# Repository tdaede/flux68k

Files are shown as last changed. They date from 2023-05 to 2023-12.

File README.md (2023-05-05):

flux68k
=======

The flux68k is an adapter board that allows usage of Gotek floppy drive emulators running [FlashFloppy](https://github.com/keirf/flashfloppy) firmware with the Sharp X68000 line of computers.

Requirements
------------

1. Two Gotek floppy emulators based on the AT32F435 with SFRKC30.AT4.35 PCB revision (sold as FlashFloppy+ compatible).

2. Two USB flash drives.

3. flux68k PCB.

4. DC +5V power supply with a 6x2.1mm center positive barrel jack (unless using auto switch board)

5. Male to male DB37 cable.

Installation
------------

1. Set the jumpers on each of the Gotek emulators to S0 and MOR.

2. Install the emulators into the flux68k PCB, being careful to line up the power connectors.

3. Plug in the +5V power supply and ensure that both emulators power on.

4. Build the following branch of FlashFloppy, and flash it to to the Gotek. https://github.com/keirf/flashfloppy/pull/781

5. Copy the [example FF.CFG](https://github.com/keirf/flashfloppy/blob/a0a06fc15bd6ab05d6b62a67390bd5e57fd1853e/examples/FF.CFG) to each of the USB sticks and change the pin02 line to:
``` ini
pin02 = in
```

6. Set the switch on the back of the flux68k to drives 2-3.

7. Plug in the DB37 cable between the X68000 and the flux68k.

Usage
-----

Copy floppy images to the USB flash drives and access or boot from them from the X68000. More detailed information on using FlashFloppy can be found at (FlashFloppy's documentation)[https://github.com/keirf/flashfloppy/wiki].

Notes
-----

* XDF images must be renamed to have the .img extension.

* Many applications do not boot correctly from drives 2-3. For these, the rear switch must be set to drives 0-1, and the X68000's internal drives disconnected (unless the auto switch board is used, see below). On compact models, there is a switch on the back of the X68000 to switch the internal drive assigments to 2-3.

* The flux68k must be powered when attached to the X68000 or floppies may not read correctly.

* FlashFloppy currently ignores the motorized eject signal, so the floppy must be manually ejected (by pushing the rotary knob) if an application tries to automatically eject a floppy.

Auto switch board
=================

Optionally, a mod can be installed on non-compact models to automatically switch the internal floppy drive assignments. In addition, this board will also supply power to the external floppy emulators, so that an external power supply is not needed.

Requirements
------------

1. Auto switcher board

2. 34 pin IDC cable, at least 20cm Long

3. +5V internal power cable, either a [Molex to berg connector cable](https://www.crystalfontz.com/product/wrpwry12-four-pin-power-splitter-cable) or a custom made cable that attaches to one of the 3 pin berg connections for the floppy drives or HDD.

Installation
------------

1. Remove the left panel of the X68000.

2. Disconnect the SCSI cable from the external SCSI connector PCB, if present.

3. Disconnect the floppy cable from the external floppy connector PCB.

4. Unscrew and remove the SCSI/floppy connector module via the two plastic tapping screws holding it in place.

5. Remove the SCSI connector PCB from the module by removing the two machine screws holding it in place.

6. Remove the floppy connector PCB from the mdoule by removing the two machine screws holding it in place. Note the relative positions of the bracket and EMI shielding.

7. Attach the new 34 pin IDC cable to the "MB" connector on the auto switcher PCB.

8. Attach the +5V power cable to the swapper PCB.

9. Install the auto switcher PCB on the original metal bracket / EMI shield using the two machine screws.

10. Install the SCSI connector board (if present) on top of the swapper PCB with two machine screws.

11. Install the external connector module back into the X68000 using the two plastic tapping screws.

12. Attach the +5V cable to the appropriate location (the molex connector if using a molex to berg cable).

13. Connect the existing 34 pin floppy IDC cable coming off of the floppy drives to the "FD" connector on the swapper PCB.

14. Disconnect the other end of the existing 34 pin floppy IDC cable from the motherboard connector at the base of the X68000. Leave this disconnected inside the machine.

15. Connect the other end of the new 34 pin IDC cable (connected to the "MB" connector on the switcher PCB) to the motherboard connector at the base of the X68000.

16. Reinstall the left panel of the X68000.

Notes
-----

* The auto switcher PCB uses the previously unused pin 3 of the 37-pin connector as the switch signal. When left floating or high, it switches the internal drives to 0-1. When pulled low, it switches the internal drives to 2-3.

* The auto swticher PCB uses unused pins 18 and 19 of the 37-pin connector to send +5V power to the external floppy emulator. Each pin is protected by a 250mA PTC fuse.

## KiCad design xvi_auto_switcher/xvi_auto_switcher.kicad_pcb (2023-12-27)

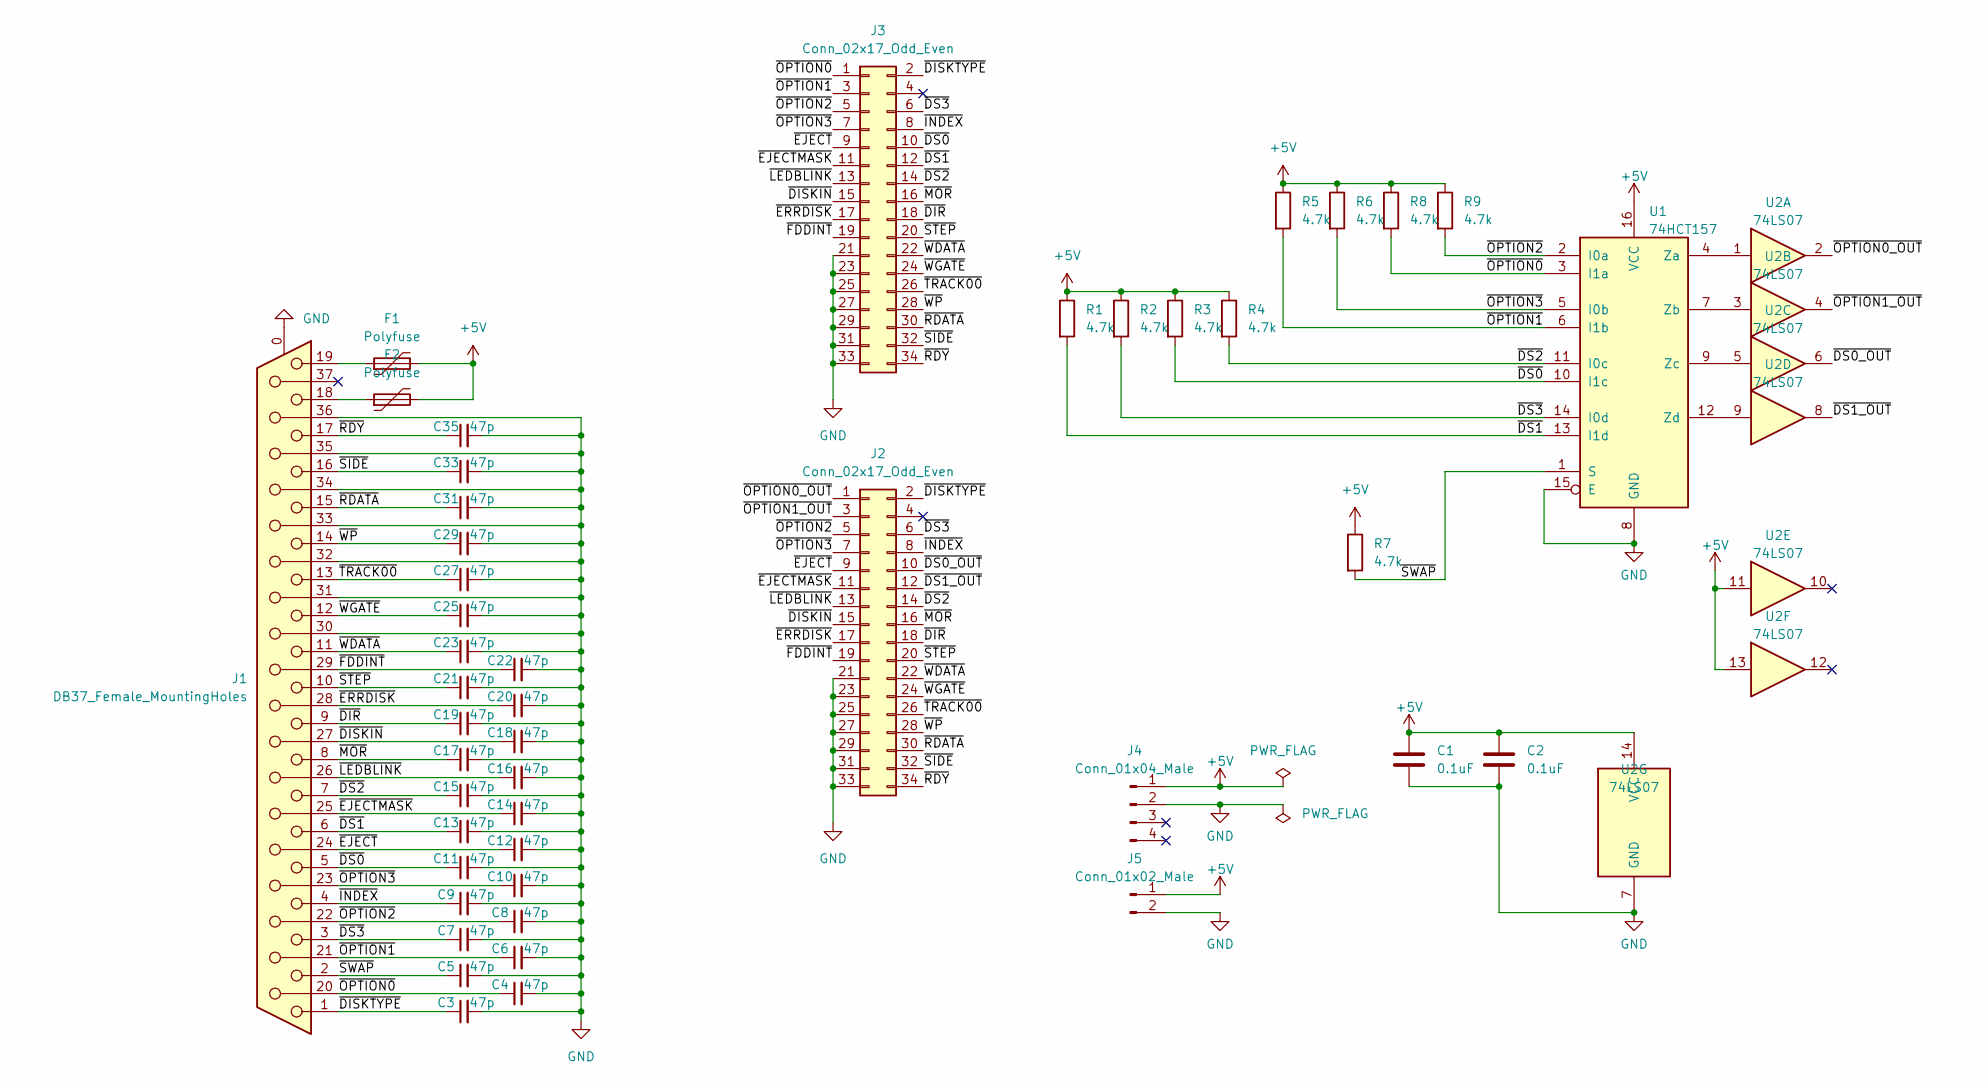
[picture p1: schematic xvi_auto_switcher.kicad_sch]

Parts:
C1, C2: 0.1uF; C_0603_1608Metric; Digikey 311-1088-1-ND
C3, C4, C5, C6, C7, C8, C9, C10, C11, C12, C13, C14, C15, C16, C17, C18, C19, C20, C21, C22, C23, C25, C27, C29, C31, C33, C35: 47p; C_0603_1608Metric; Digikey 311-1065-1-ND
F1, F2: Polyfuse; R_1206_3216Metric; Digikey 507-1799-1-ND
J1: DB37_Female_MountingHoles; DSUB-37_Female_Horizontal_P2.77x2.84mm_EdgePinOffset7.70mm_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; Digikey A32114-ND
J2, J3: Conn_02x17_Odd_Even; IDC-Header_2x17_P2.54mm_Vertical; Digikey ED10528-ND
J4: Conn_01x04_Male; PinHeader_1x04_P2.54mm_Horizontal; Digikey A112643-ND
J5: Conn_01x02_Male; PinHeader_1x02_P2.54mm_Vertical; Digikey DNP
R1, R2, R3, R4, R5, R6, R7, R8, R9: 4.7k; R_0603_1608Metric; Digikey 311-4.70KHRCT-ND
U1: 74HCT157; SOIC-16_3.9x9.9mm_P1.27mm; Digikey 296-31835-1-ND
U2: 74LS07; SOIC-14_3.9x8.7mm_P1.27mm; Digikey 296-14877-1-ND

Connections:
+5V: C1.1, C2.1, F1.2, F2.2, J4.1, J5.1, R1.1, R2.1, R3.1, R4.1, R5.1, R6.1, R7.1, R8.1, R9.1, U1.16 (VCC), U2.11, U2.13, U2.14 (VCC)
/~DIR: C19.1, J1.9, J2.18, J3.18
/~DISKIN: C18.1, J1.27, J2.15, J3.15
/~DISKTYPE: C3.1, J1.1, J2.2, J3.2
/~DS0_OUT: J2.10, U2.6
/~DS0: C11.1, J1.5, J3.10, R3.2, U1.10 (I1c)
/~DS1_OUT: J2.12, U2.8
/~DS1: C13.1, J1.6, J3.12, R1.2, U1.13 (I1d)
/~DS2: C15.1, J1.7, J2.14, J3.14, R4.2, U1.11 (I0c)
/~DS3: C7.1, J1.3, J2.6, J3.6, R2.2, U1.14 (I0d)
/~EJECTMASK: C14.1, J1.25, J2.11, J3.11
/~EJECT: C12.1, J1.24, J2.9, J3.9
/~ERRDISK: C20.1, J1.28, J2.17, J3.17
/~FDDINT: C22.1, J1.29, J2.19, J3.19
/~INDEX: C9.1, J1.4, J2.8, J3.8
/~LEDBLINK: C16.1, J1.26, J2.13, J3.13
/~MOR: C17.1, J1.8, J2.16, J3.16
/~OPTION0_OUT: J2.1, U2.2
/~OPTION0: C4.1, J1.20, J3.1, R8.2, U1.3 (I1a)
/~OPTION1_OUT: J2.3, U2.4
/~OPTION1: C6.1, J1.21, J3.3, R5.2, U1.6 (I1b)
/~OPTION2: C8.1, J1.22, J2.5, J3.5, R9.2, U1.2 (I0a)
/~OPTION3: C10.1, J1.23, J2.7, J3.7, R6.2, U1.5 (I0b)
/~RDATA: C31.1, J1.15, J2.30, J3.30
/~RDY: C35.1, J1.17, J2.34, J3.34
/~SIDE: C33.1, J1.16, J2.32, J3.32
/~STEP: C21.1, J1.10, J2.20, J3.20
/~SWAP: C5.1, J1.2, R7.2, U1.1 (S)
/~TRACK00: C27.1, J1.13, J2.26, J3.26
/~WDATA: C23.1, J1.11, J2.22, J3.22
/~WGATE: C25.1, J1.12, J2.24, J3.24
/~WP: C29.1, J1.14, J2.28, J3.28
GND: C1.2, C2.2, C3.2, C4.2, C5.2, C6.2, C7.2, C8.2, C9.2, C10.2, C11.2, C12.2, C13.2, C14.2, C15.2, C16.2, C17.2, C18.2, C19.2, C20.2, C21.2, C22.2, C23.2, C25.2, C27.2, C29.2, C31.2, C33.2, C35.2, J1.0 (PAD), J1.30, J1.31, J1.32, J1.33, J1.34, J1.35, J1.36, J2.21, J2.23, J2.25, J2.27, J2.29, J2.31, J2.33, J3.21, J3.23, J3.25, J3.27, J3.29, J3.31, J3.33, J4.2, J5.2, U1.8 (GND), U1.15 (E), U2.7 (GND)
unnamed: F1.1, J1.19
unnamed: F2.1, J1.18
unnamed: U1.4 (Za), U2.1
unnamed: U1.7 (Zb), U2.3
unnamed: U1.9 (Zc), U2.5
unnamed: U1.12 (Zd), U2.9

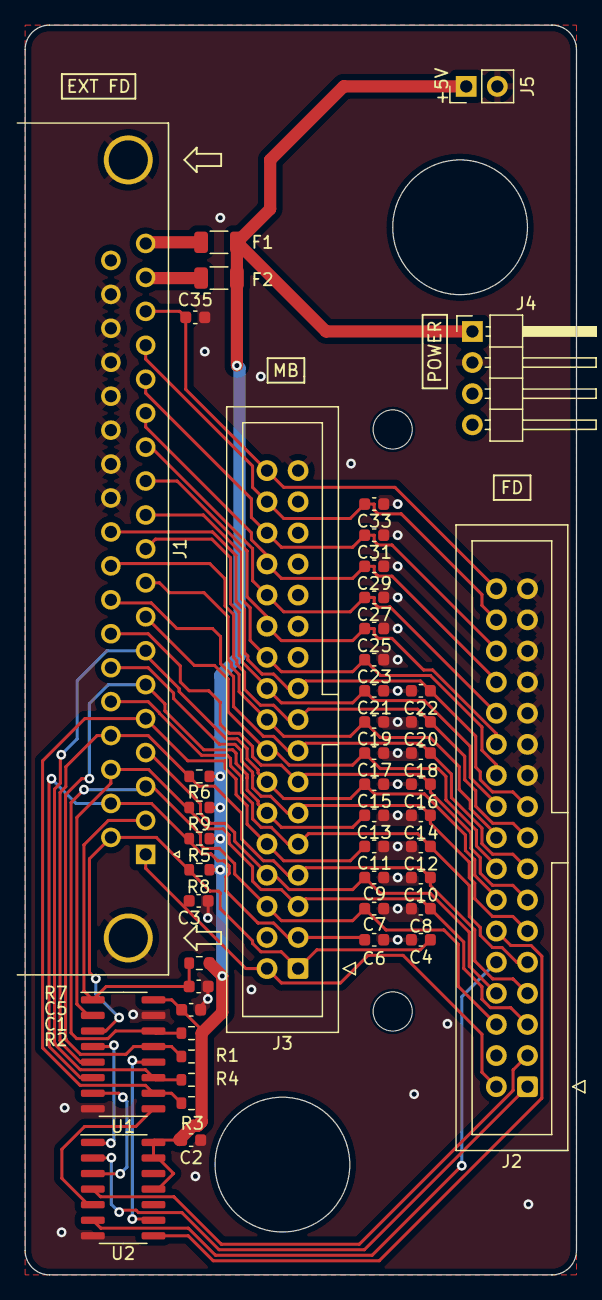
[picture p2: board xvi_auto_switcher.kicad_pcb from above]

Board: 2 copper layers, 45.0 x 102.0 mm, 47 parts (0 on the bottom side), 39 nets.

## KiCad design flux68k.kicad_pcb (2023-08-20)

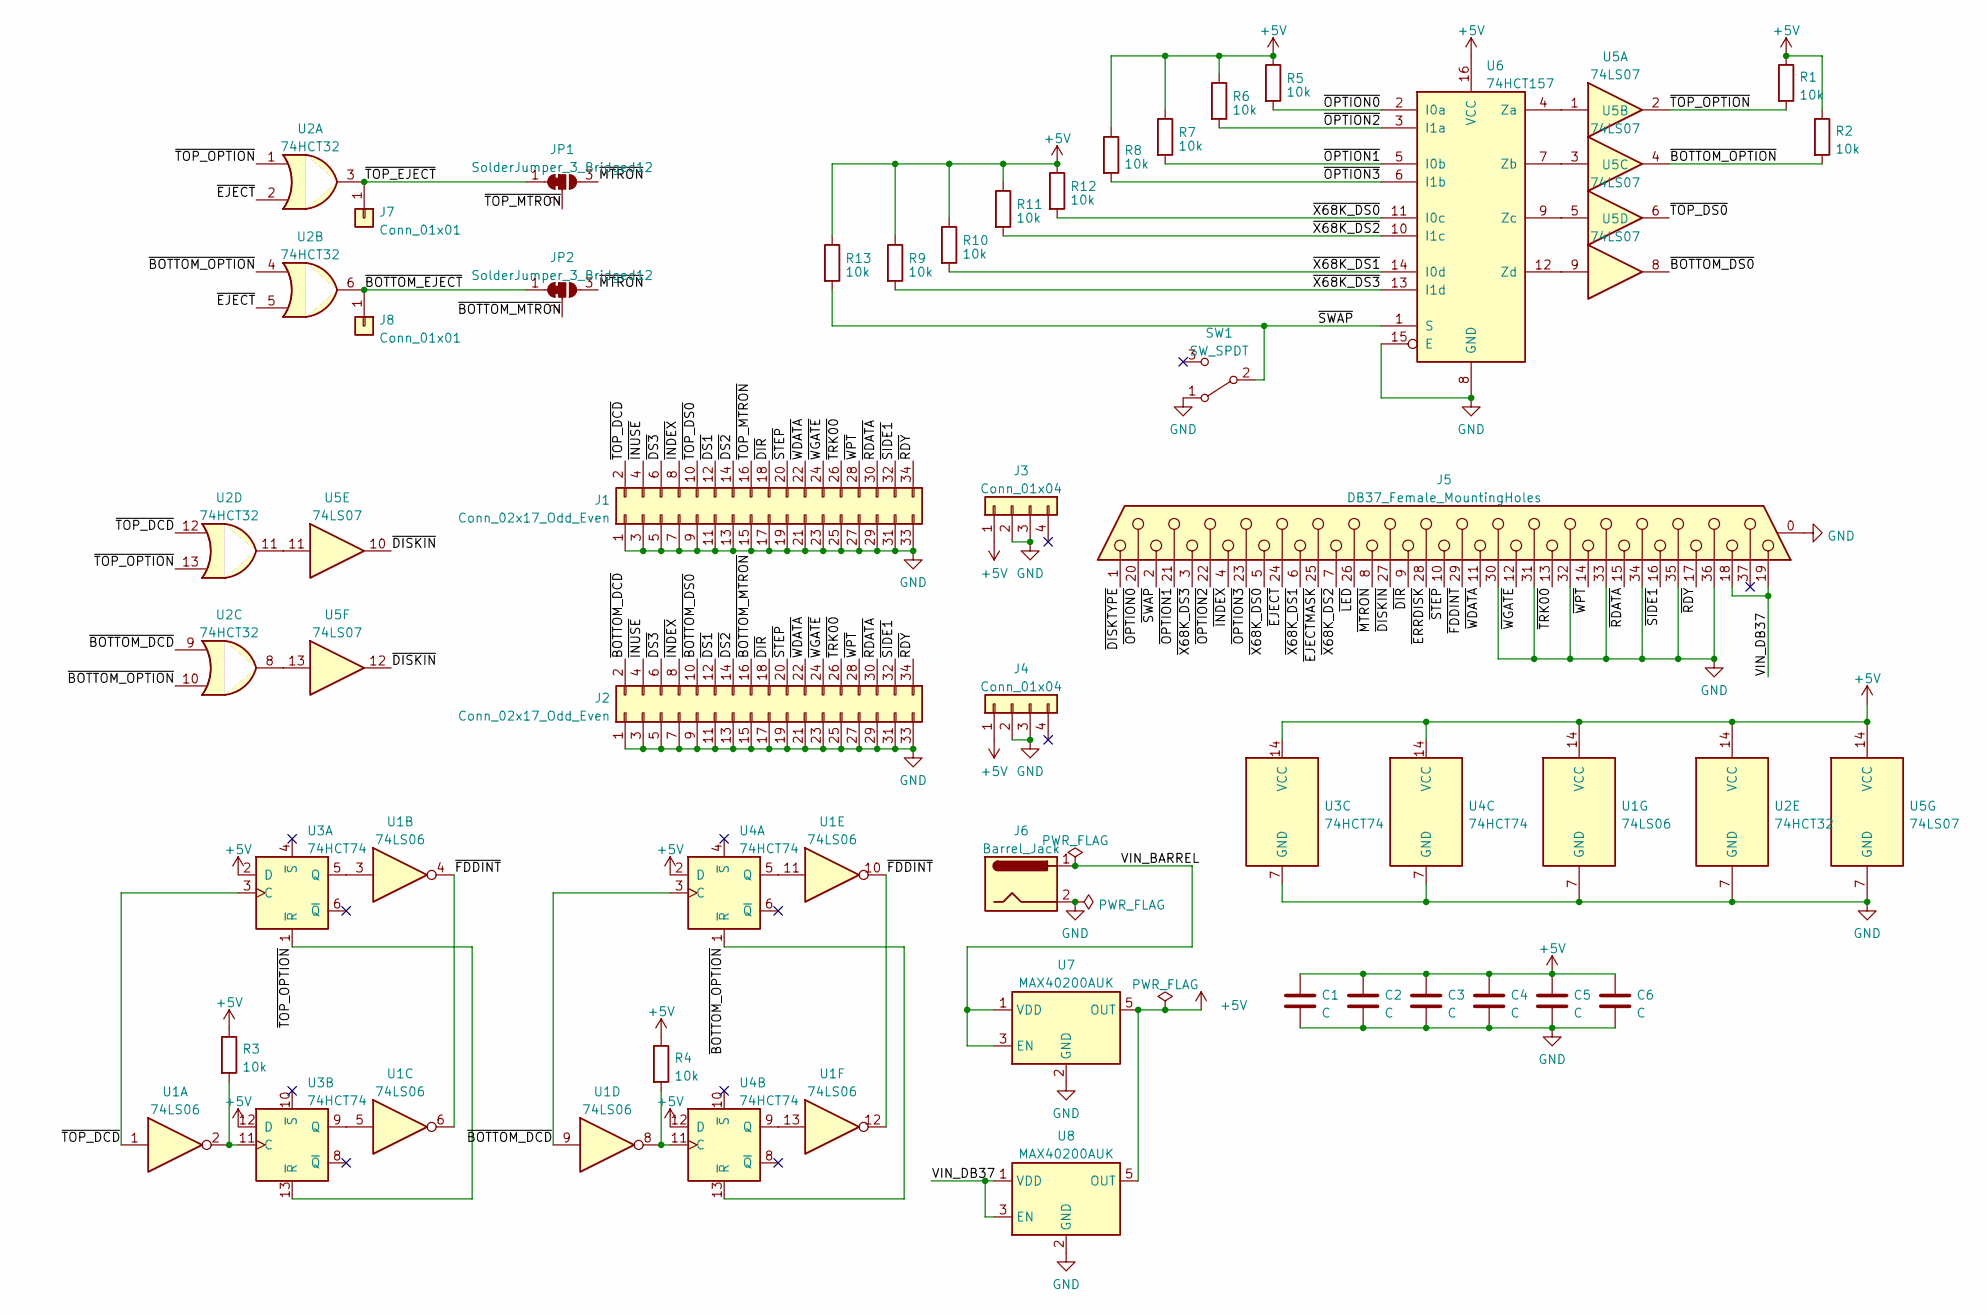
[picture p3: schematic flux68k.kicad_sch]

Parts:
C1, C2, C3, C4, C5, C6: C; C_0805_2012Metric_Pad1.18x1.45mm_HandSolder; Digikey 311-1140-1-ND
J1, J2: Conn_02x17_Odd_Even; PinSocket_2x17_P2.54mm_Vertical; Digikey S9199-ND
J3, J4: Conn_01x04; PinSocket_1x04_P2.54mm_Vertical; Digikey S7037-ND
J5: DB37_Female_MountingHoles; DSUB-37_Female_Vertical_P2.77x2.84mm_MountingHoles; Digikey L77SDCH37SOL2-ND
J6: Barrel_Jack; PJ-044AH; Digikey CP-044AH-ND
J7, J8: Conn_01x01; PinSocket_1x01_P2.54mm_Vertical; Digikey DNP
JP1, JP2: SolderJumper_3_Bridged12; SolderJumper-3_P1.3mm_Bridged2Bar12_Pad1.0x1.5mm; Digikey DNP
R1, R2, R3, R4, R5, R6, R7, R8, R9, R10, R11, R12, R13: 10k; R_0805_2012Metric_Pad1.20x1.40mm_HandSolder; Digikey 311-10.0KCRCT-ND
SW1: SW_SPDT; SW_Slide_1P2T_CK_OS102011MS2Q; Digikey CKN12284-ND
U1: 74LS06; SOIC-14_3.9x8.7mm_P1.27mm; Digikey 296-14876-1-ND
U2: 74HCT32; SOIC-14_3.9x8.7mm_P1.27mm; Digikey 296-14868-1-ND
U3, U4: 74HCT74; SOIC-14_3.9x8.7mm_P1.27mm; Digikey 296-1211-1-ND
U5: 74LS07; SOIC-14_3.9x8.7mm_P1.27mm; Digikey 296-14877-1-ND
U6: 74HCT157; SOIC-16_3.9x9.9mm_P1.27mm; Digikey 296-31835-1-ND
U7, U8: MAX40200AUK; SOT-23-5; Digikey MAX40200AUK+TCT-ND

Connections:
+5V: C1.1, C2.1, C3.1, C4.1, C5.1, C6.1, J3.1, J4.1, R1.1, R2.1, R3.1, R4.1, R5.1, R6.1, R7.1, R8.1, R9.1, R10.1, R11.1, R12.1, R13.1, U1.14 (VCC), U2.14 (VCC), U3.2 (D), U3.12 (D), U3.14 (VCC), U4.2 (D), U4.12 (D), U4.14 (VCC), U5.14 (VCC), U6.16 (VCC), U7.5 (OUT), U8.5 (OUT)
/VIN_BARREL: J6.1, U7.1 (VDD), U7.3 (EN)
/VIN_DB37: J5.18, J5.19, U8.1 (VDD), U8.3 (EN)
/~BOTTOM_DCD: J2.2, U1.9, U2.9, U4.3 (C)
/~BOTTOM_DS0: J2.10, U5.8
/~BOTTOM_EJECT: J8.1, JP2.1 (A), U2.6
/~BOTTOM_MTRON: J2.16, JP2.2 (C)
/~BOTTOM_OPTION: R2.2, U2.4, U2.10, U4.1 (~R), U4.13 (~R), U5.4
/~DIR: J1.18, J2.18, J5.9
/~DISKIN: J5.27, U5.10, U5.12
/~DISKTYPE: J5.1
/~DS1: J1.12, J2.12
/~DS2: J1.14, J2.14
/~DS3: J1.6, J2.6
/~EJECTMASK: J5.25
/~EJECT: J5.24, U2.2, U2.5
/~ERRDISK: J5.28
/~FDDINT: J5.29, U1.4, U1.6, U1.10, U1.12
/~INDEX: J1.8, J2.8, J5.4
/~INUSE: J1.4, J2.4
/~LED: J5.26
/~MTRON: J5.8, JP1.3 (B), JP2.3 (B)
/~OPTION0: J5.20, R5.2, U6.2 (I0a)
/~OPTION1: J5.21, R7.2, U6.5 (I0b)
/~OPTION2: J5.22, R6.2, U6.3 (I1a)
/~OPTION3: J5.23, R8.2, U6.6 (I1b)
/~RDATA: J1.30, J2.30, J5.15
/~RDY: J1.34, J2.34, J5.17
/~SIDE1: J1.32, J2.32, J5.16
/~STEP: J1.20, J2.20, J5.10
/~SWAP: J5.2, R13.2, SW1.2 (B), U6.1 (S)
/~TOP_DCD: J1.2, U1.1, U2.12, U3.3 (C)
/~TOP_DS0: J1.10, U5.6
/~TOP_EJECT: J7.1, JP1.1 (A), U2.3
/~TOP_MTRON: J1.16, JP1.2 (C)
/~TOP_OPTION: R1.2, U2.1, U2.13, U3.1 (~R), U3.13 (~R), U5.2
/~TRK00: J1.26, J2.26, J5.13
/~WDATA: J1.22, J2.22, J5.11
/~WGATE: J1.24, J2.24, J5.12
/~WPT: J1.28, J2.28, J5.14
/~X68K_DS0: J5.5, R12.2, U6.11 (I0c)
/~X68K_DS1: J5.6, R10.2, U6.14 (I0d)
/~X68K_DS2: J5.7, R11.2, U6.10 (I1c)
/~X68K_DS3: J5.3, R9.2, U6.13 (I1d)
GND: C1.2, C2.2, C3.2, C4.2, C5.2, C6.2, J1.1, J1.3, J1.5, J1.7, J1.9, J1.11, J1.13, J1.15, J1.17, J1.19, J1.21, J1.23, J1.25, J1.27, J1.29, J1.31, J1.33, J2.1, J2.3, J2.5, J2.7, J2.9, J2.11, J2.13, J2.15, J2.17, J2.19, J2.21, J2.23, J2.25, J2.27, J2.29, J2.31, J2.33, J3.2, J3.3, J4.2, J4.3, J5.0 (PAD), J5.30, J5.31, J5.32, J5.33, J5.34, J5.35, J5.36, J6.2, SW1.1 (A), U1.7 (GND), U2.7 (GND), U3.7 (GND), U4.7 (GND), U5.7 (GND), U6.8 (GND), U6.15 (E), U7.2 (GND), U8.2 (GND)
unnamed: U2.8, U5.13
unnamed: U2.11, U5.11
unnamed: U1.3, U3.5 (Q)
unnamed: R3.2, U1.2, U3.11 (C)
unnamed: U1.5, U3.9 (Q)
unnamed: U1.11, U4.5 (Q)
unnamed: R4.2, U1.8, U4.11 (C)
unnamed: U1.13, U4.9 (Q)
unnamed: U5.1, U6.4 (Za)
unnamed: U5.3, U6.7 (Zb)
unnamed: U5.5, U6.9 (Zc)
unnamed: U5.9, U6.12 (Zd)

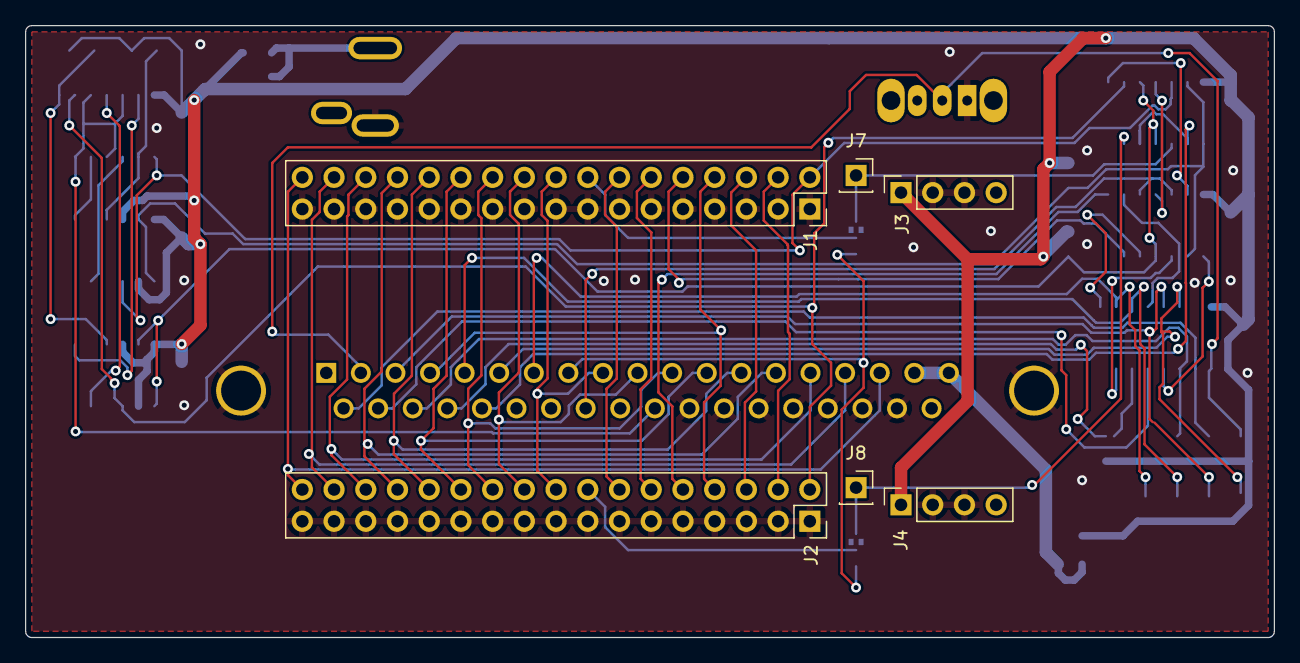
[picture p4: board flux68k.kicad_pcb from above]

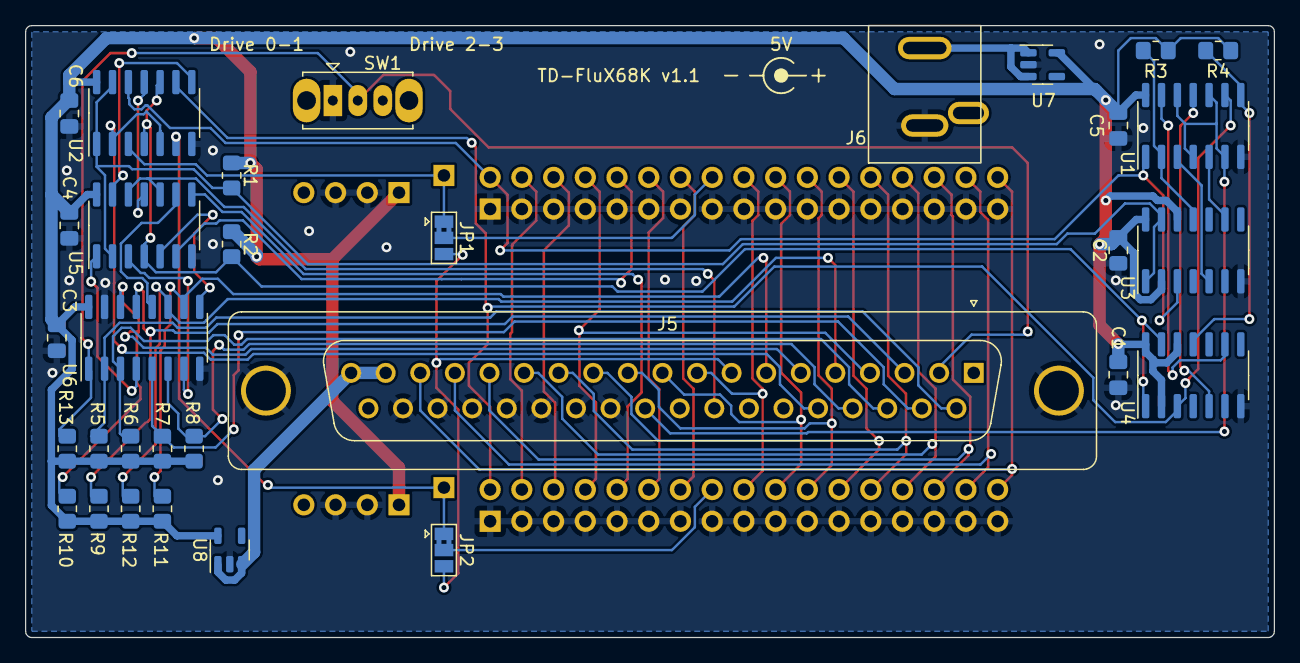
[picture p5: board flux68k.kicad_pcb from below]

Board: 2 copper layers, 100.0 x 49.0 mm, 38 parts (32 on the bottom side), 53 nets.

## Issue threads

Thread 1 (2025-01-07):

Eject via Motor-On

hkr, 2025-01-07:
Hi,

in https://github.com/keirf/flashfloppy/pull/781#issuecomment-1520632195 you mentioned that you want to try to trigger eject via the Motor-On line. Have you ever tried this with the v1.1 flux68k board and is this change already in your fork of FlashFloppy?

Thanks

tdaede, 2025-01-23:
I never tried it and it's not implemented. It's not a huge deal right now as you can just push the button to eject once an application turns on the eject motor.

hkr, 2025-01-25:
I tried to use the eject signal via motor-on in FlashFloppy but couldn't get it to work. With a logic analyzer it looked like I'm only getting a very short /EJECT (3.5 microseconds) and it didn't trigger an interrupt (even though I tried to enable it for the MO pin 12).

Unrelated but I did add support for X68000-style XDF and DIM floppy images here: https://github.com/hkr/flashfloppy/commit/2c73f75054e6dee67235de7c6cdf2fd2da7378dd

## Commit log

2023-04-22 Add xvi auto switcher board.
    [xvi_auto_switcher.kicad_pcb, xvi_auto_switcher.kicad_sch]
2023-04-22 add missing flux68k pullups
    [flux68k.kicad_sch]
2023-05-05 add docs for auto switcher pcb
2023-07-30 update auto switcher pcb connector positions and add caps
    [xvi_auto_switcher.kicad_pcb, xvi_auto_switcher.kicad_sch]
2023-07-30 add pullups and ideal diodes to flux68k
    [flux68k.kicad_pcb, flux68k.kicad_sch]
2023-08-20 shrink board by 1mm
    [flux68k.kicad_pcb]
2023-08-20 generate flux68k 1.1
    [flux68k.kicad_pcb, xvi_auto_switcher.kicad_pcb]

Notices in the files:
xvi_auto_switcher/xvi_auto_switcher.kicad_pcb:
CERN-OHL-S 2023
